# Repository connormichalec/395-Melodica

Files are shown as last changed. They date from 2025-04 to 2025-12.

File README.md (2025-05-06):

# 395-Melodica

Current setup, Key decoding (and to midi) on the smaller stm chip, looping jankily combined on bigger stm chip that was originally just going to be used for synthesis. Smaller ship sends midi data to synthesis. Synthesis manages looping and sends back midi data for smaller one to route to the output. TODO: Either re-seperate using a smaller chip with bigger ram (ideal). Or just get rid of smaller one together.

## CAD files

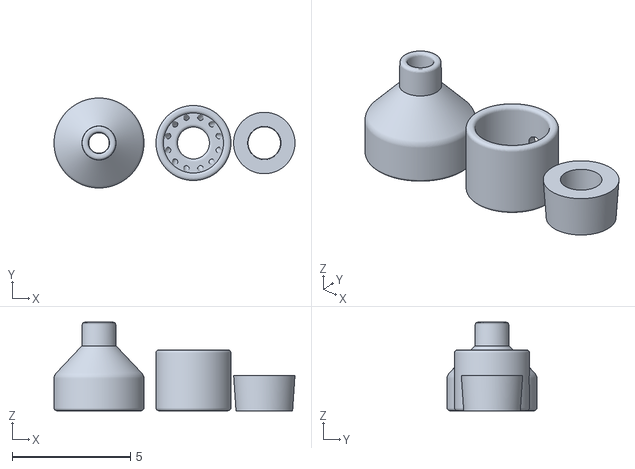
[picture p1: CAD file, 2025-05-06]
3D_Print_files/breath sensor 2.stl
10.2 x 3.81 x 3.75

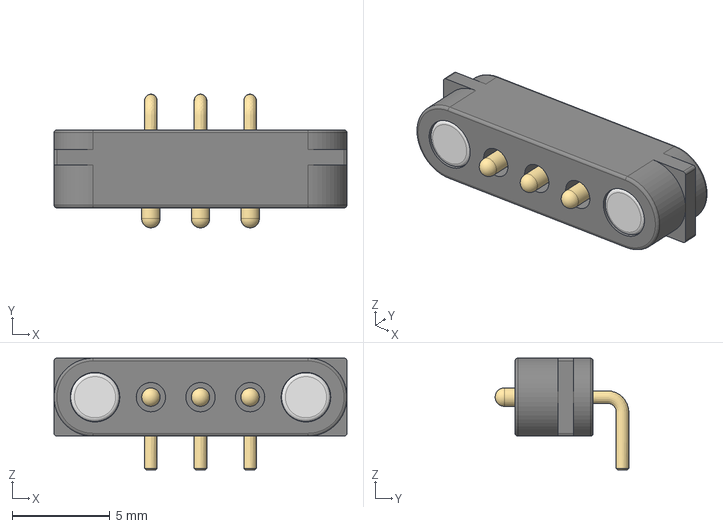
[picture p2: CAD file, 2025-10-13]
PCBs/V2/Switchbox/V1_Prototype_template/Symbols_footprints/5360/3D/5360.stp
15.0 x 6.84 x 5.73 mm

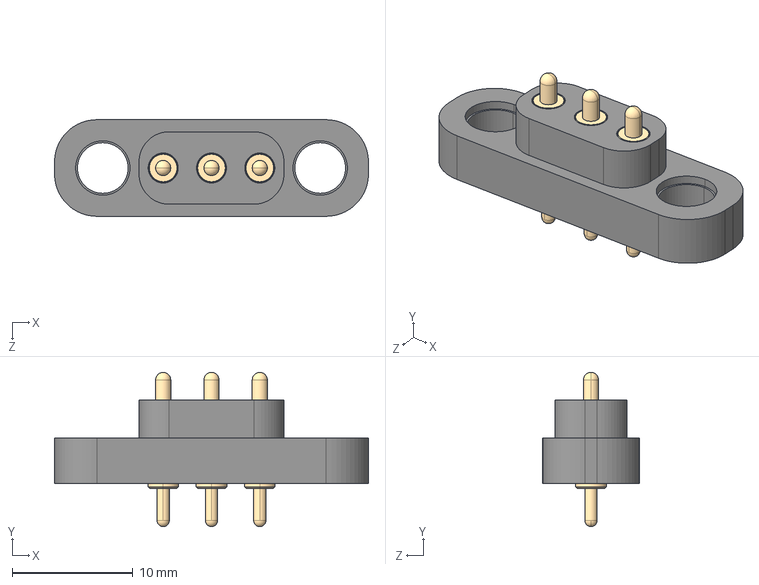
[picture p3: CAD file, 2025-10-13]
PCBs/V2/Switchbox/V1_Prototype_template/Symbols_footprints/858-22-003-10-001101/3D/858-22-003-10-001101.stp
26.0 x 12.8 x 8.00 mm
mill-max-858-22-003-10-001101_P8XX-18-014-16-08000X(P803-18-014-16-080000)
mill-max-858-22-003-10-001101_0858 x 3

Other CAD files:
PCBs/V2/Switchbox/V1_Prototype_template/Symbols_footprints/5360/Allegro/5360.psm
PCBs/V2/Switchbox/V1_Prototype_template/Symbols_footprints/5360/DEHDL/5360/chips/chips.prt
PCBs/V2/Switchbox/V1_Prototype_template/Symbols_footprints/858-22-003-10-001101/Allegro/8582200310001101.psm
PCBs/V2/Switchbox/V1_Prototype_template/Symbols_footprints/858-22-003-10-001101/DEHDL/858_22_003_10_001101/chips/chips.prt

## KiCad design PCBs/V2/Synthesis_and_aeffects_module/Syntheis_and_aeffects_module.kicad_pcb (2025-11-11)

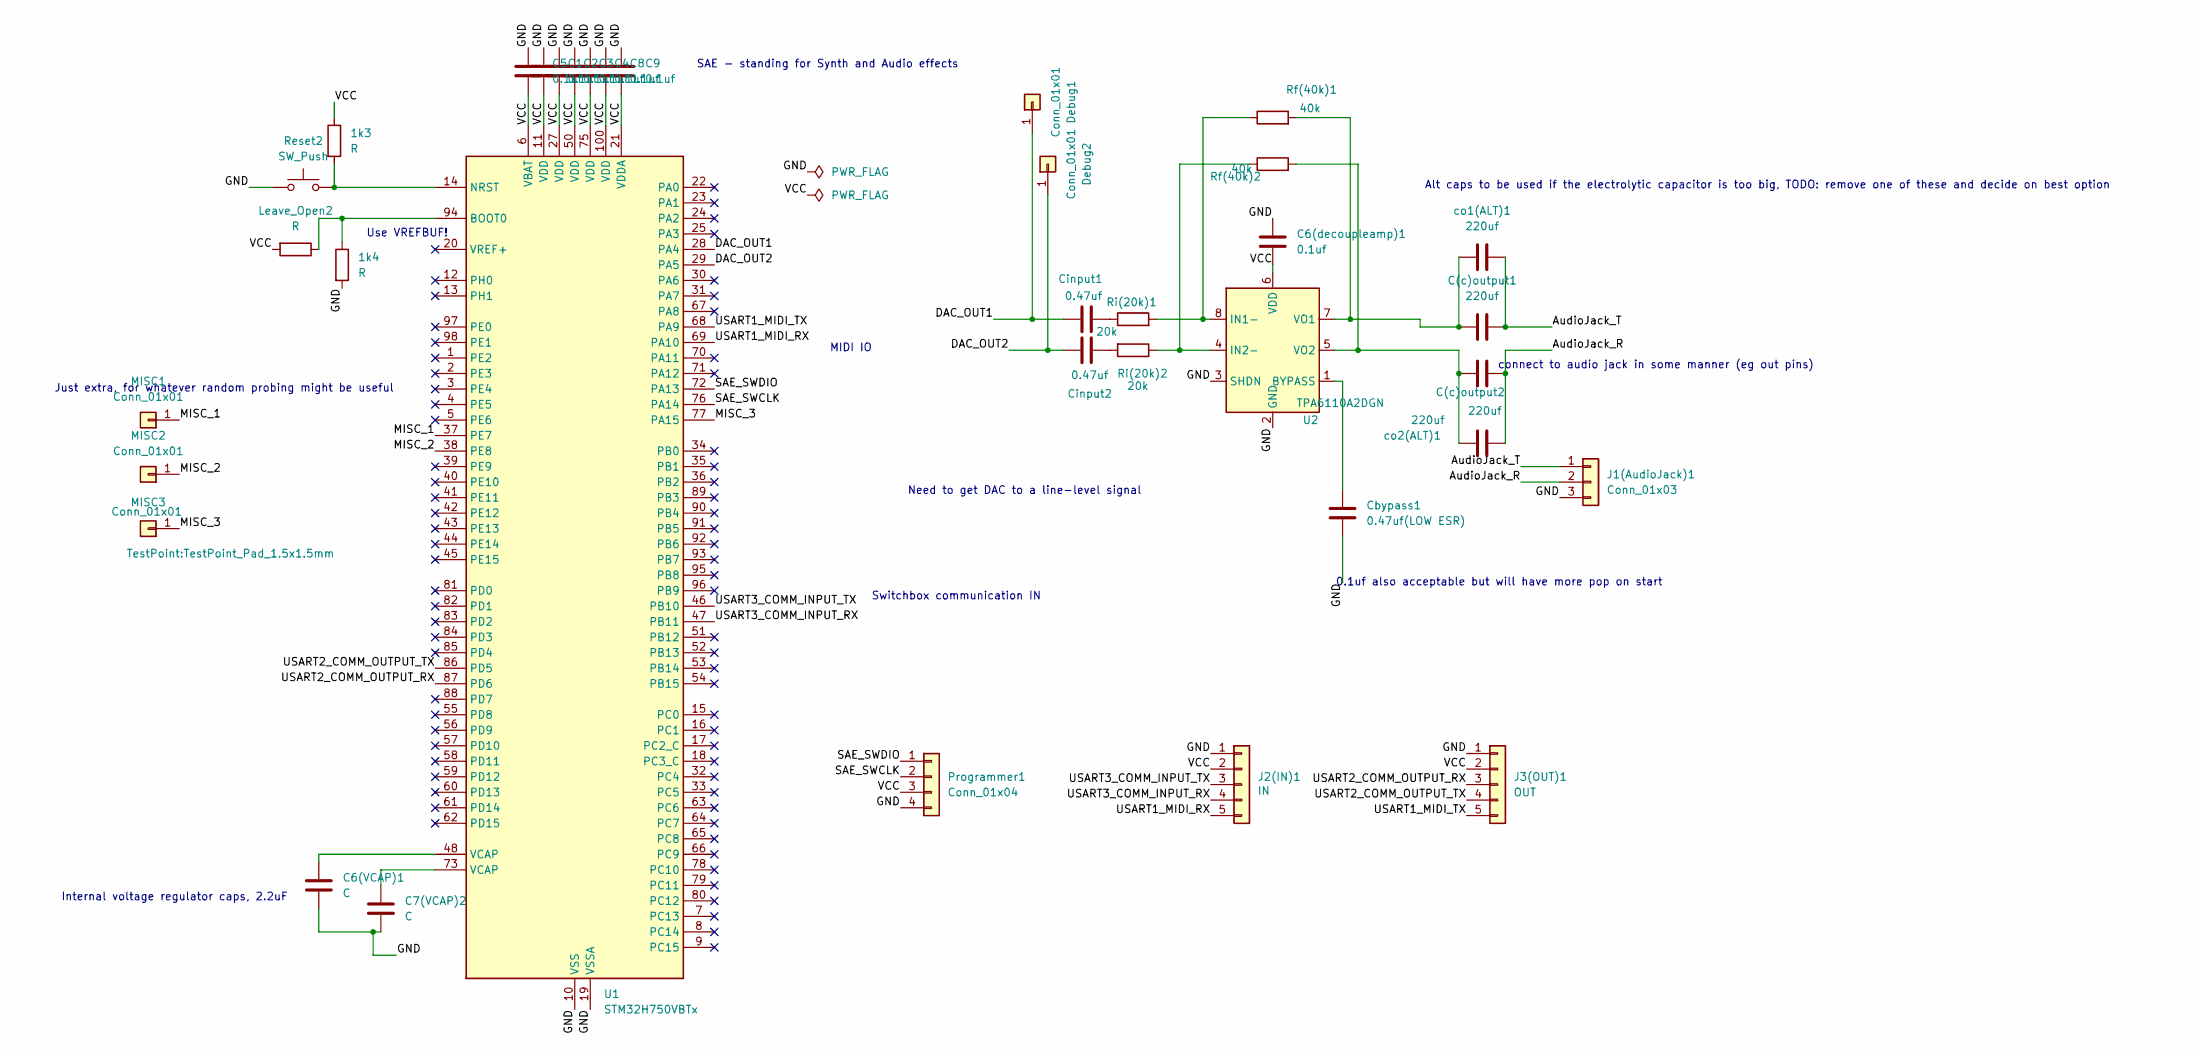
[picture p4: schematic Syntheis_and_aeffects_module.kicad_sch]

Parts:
1k3, 1k4: R; R_0603_1608Metric_Pad0.98x0.95mm_HandSolder
C1, C2, C3, C4, C5, C6(decoupleamp)1, C8, C9: 0.1uf; C_0603_1608Metric_Pad1.08x0.95mm_HandSolder
C6(VCAP)1, C7(VCAP)2: C; C_0603_1608Metric_Pad1.08x0.95mm_HandSolder
C(c)output1, C(c)output2: 220uf; CP_Radial_D5.0mm_P2.00mm
Cbypass1: 0.47uf(LOW ESR); C_0603_1608Metric_Pad1.08x0.95mm_HandSolder
Cinput1, Cinput2: 0.47uf; C_0603_1608Metric_Pad1.08x0.95mm_HandSolder
Debug1, Debug2: Conn_01x01; TestPoint_Pad_1.5x1.5mm
J1(AudioJack)1: Conn_01x03; PinHeader_1x03_P2.54mm_Vertical
J2(IN)1: IN; PinHeader_1x05_P2.54mm_Vertical
J3(OUT)1: OUT; PinHeader_1x05_P2.54mm_Vertical
Leave_Open2: R; R_Axial_DIN0204_L3.6mm_D1.6mm_P7.62mm_Horizontal
MISC1, MISC2, MISC3: Conn_01x01; TestPoint_Pad_1.5x1.5mm
Programmer1: Conn_01x04; PinHeader_1x04_P2.54mm_Vertical
Reset2: SW_Push; SW_PUSH_6mm_H4.3mm
Rf(40k)1, Rf(40k)2: 40k; R_Axial_DIN0207_L6.3mm_D2.5mm_P10.16mm_Horizontal
Ri(20k)1, Ri(20k)2: 20k; R_Axial_DIN0207_L6.3mm_D2.5mm_P10.16mm_Horizontal
U1: STM32H750VBTx; LQFP-100_14x14mm_P0.5mm
U2: TPA6110A2DGN; HVSSOP-8-1EP_3x3mm_P0.65mm_EP1.57x1.89mm
co1(ALT)1, co2(ALT)1: 220uf; C_1206_3216Metric_Pad1.33x1.80mm_HandSolder

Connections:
/AudioJack_R: C(c)output2.2, J1(AudioJack)1.2, co2(ALT)1.2
/AudioJack_T: C(c)output1.2, J1(AudioJack)1.1, co1(ALT)1.2
/DAC_OUT1: Cinput1.1, Debug1.1, U1.28 (PA4)
/DAC_OUT2: Cinput2.1, Debug2.1, U1.29 (PA5)
/GND: 1k4.2, C1.1, C2.1, C3.1, C4.1, C5.1, C6(VCAP)1.2, C6(decoupleamp)1.1, C7(VCAP)2.2, C8.1, C9.1, Cbypass1.2, J1(AudioJack)1.3, J2(IN)1.1, J3(OUT)1.1, Programmer1.4, Reset2.1, U1.10 (VSS), U1.19 (VSSA), U1.26 (VSS), U1.49 (VSS), U1.74 (VSS), U1.99 (VSS), U2.2 (GND), U2.3 (SHDN), U2.9 (GND)
/MISC_1: MISC1.1, U1.37 (PE7)
/MISC_2: MISC2.1, U1.38 (PE8)
/MISC_3: MISC3.1, U1.77 (PA15)
/SAE_SWCLK: Programmer1.2, U1.76 (PA14)
/SAE_SWDIO: Programmer1.1, U1.72 (PA13)
/USART1_MIDI_RX: J2(IN)1.5, U1.69 (PA10)
/USART1_MIDI_TX: J3(OUT)1.5, U1.68 (PA9)
/USART2_COMM_OUTPUT_RX: J3(OUT)1.3, U1.87 (PD6)
/USART2_COMM_OUTPUT_TX: J3(OUT)1.4, U1.86 (PD5)
/USART3_COMM_INPUT_RX: J2(IN)1.4, U1.47 (PB11)
/USART3_COMM_INPUT_TX: J2(IN)1.3, U1.46 (PB10)
/VCC: 1k3.1, C1.2, C2.2, C3.2, C4.2, C5.2, C6(decoupleamp)1.2, C8.2, C9.2, J2(IN)1.2, J3(OUT)1.2, Leave_Open2.2, Programmer1.3, U1.6 (VBAT), U1.11 (VDD), U1.21 (VDDA), U1.27 (VDD), U1.50 (VDD), U1.75 (VDD), U1.100 (VDD), U2.6 (VDD)
unnamed: C6(VCAP)1.1, U1.48 (VCAP)
unnamed: C7(VCAP)2.1, U1.73 (VCAP)
unnamed: Cinput1.2, Ri(20k)1.1
unnamed: Cinput2.2, Ri(20k)2.2
unnamed: 1k4.1, Leave_Open2.1, U1.94 (BOOT0)
unnamed: 1k3.2, Reset2.2, U1.14 (NRST)
unnamed: Cbypass1.1, U2.1 (BYPASS)
unnamed: Rf(40k)1.1, Ri(20k)1.2, U2.8 (IN1-)
unnamed: Rf(40k)2.1, Ri(20k)2.1, U2.4 (IN2-)
unnamed: C(c)output1.1, Rf(40k)1.2, U2.7 (VO1), co1(ALT)1.1
unnamed: C(c)output2.1, Rf(40k)2.2, U2.5 (VO2), co2(ALT)1.1

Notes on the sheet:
Switchbox communication IN
Need to get DAC to a line-level signal
connect to audio jack in some manner (eg out pins)
0.1uf also acceptable but will have more pop on start
SAE - standing for Synth and Audio effects
MIDI IO
Internal voltage regulator caps, 2.2uF
Alt caps to be used if the electrolytic capacitor is too big, TODO: remove one of these and decide on best option
Use VREFBUF!
Just extra, for whatever random probing might be useful

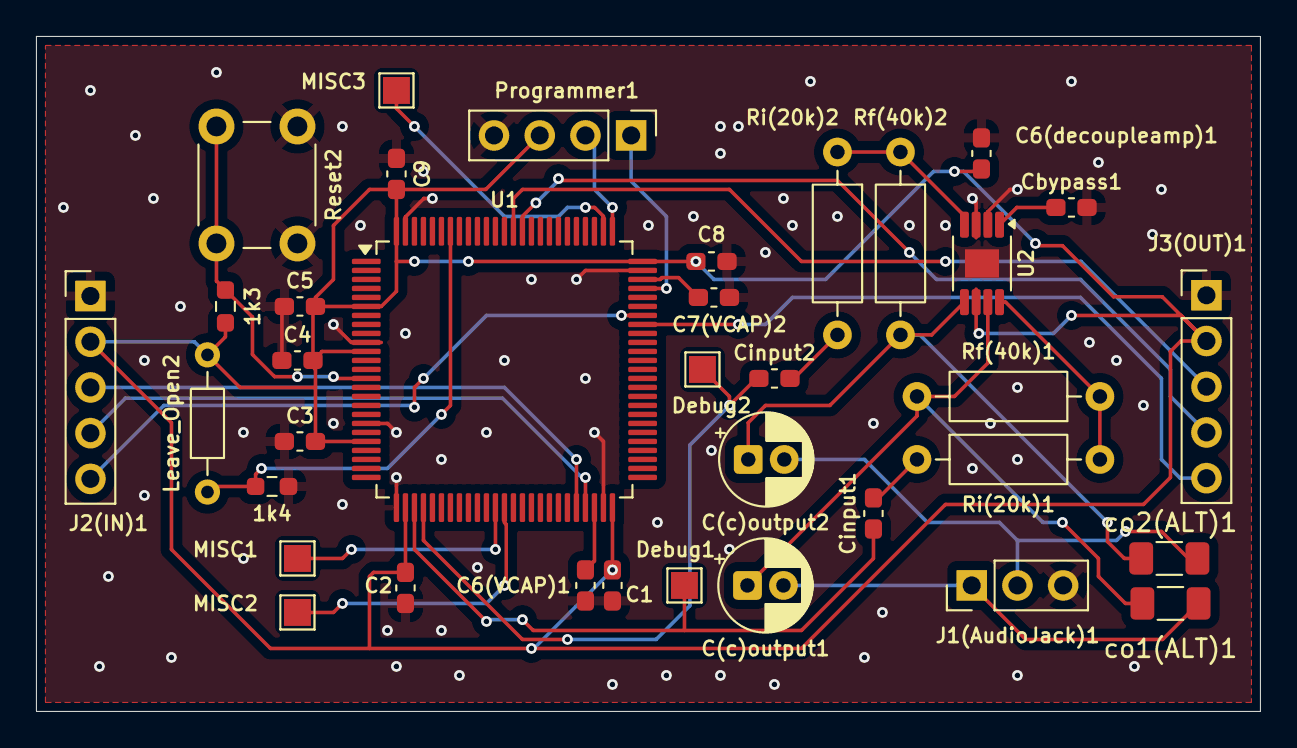
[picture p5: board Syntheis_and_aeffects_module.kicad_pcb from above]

Board: 2 copper layers, 68.0 x 37.5 mm, 36 parts (0 on the bottom side), 28 nets.

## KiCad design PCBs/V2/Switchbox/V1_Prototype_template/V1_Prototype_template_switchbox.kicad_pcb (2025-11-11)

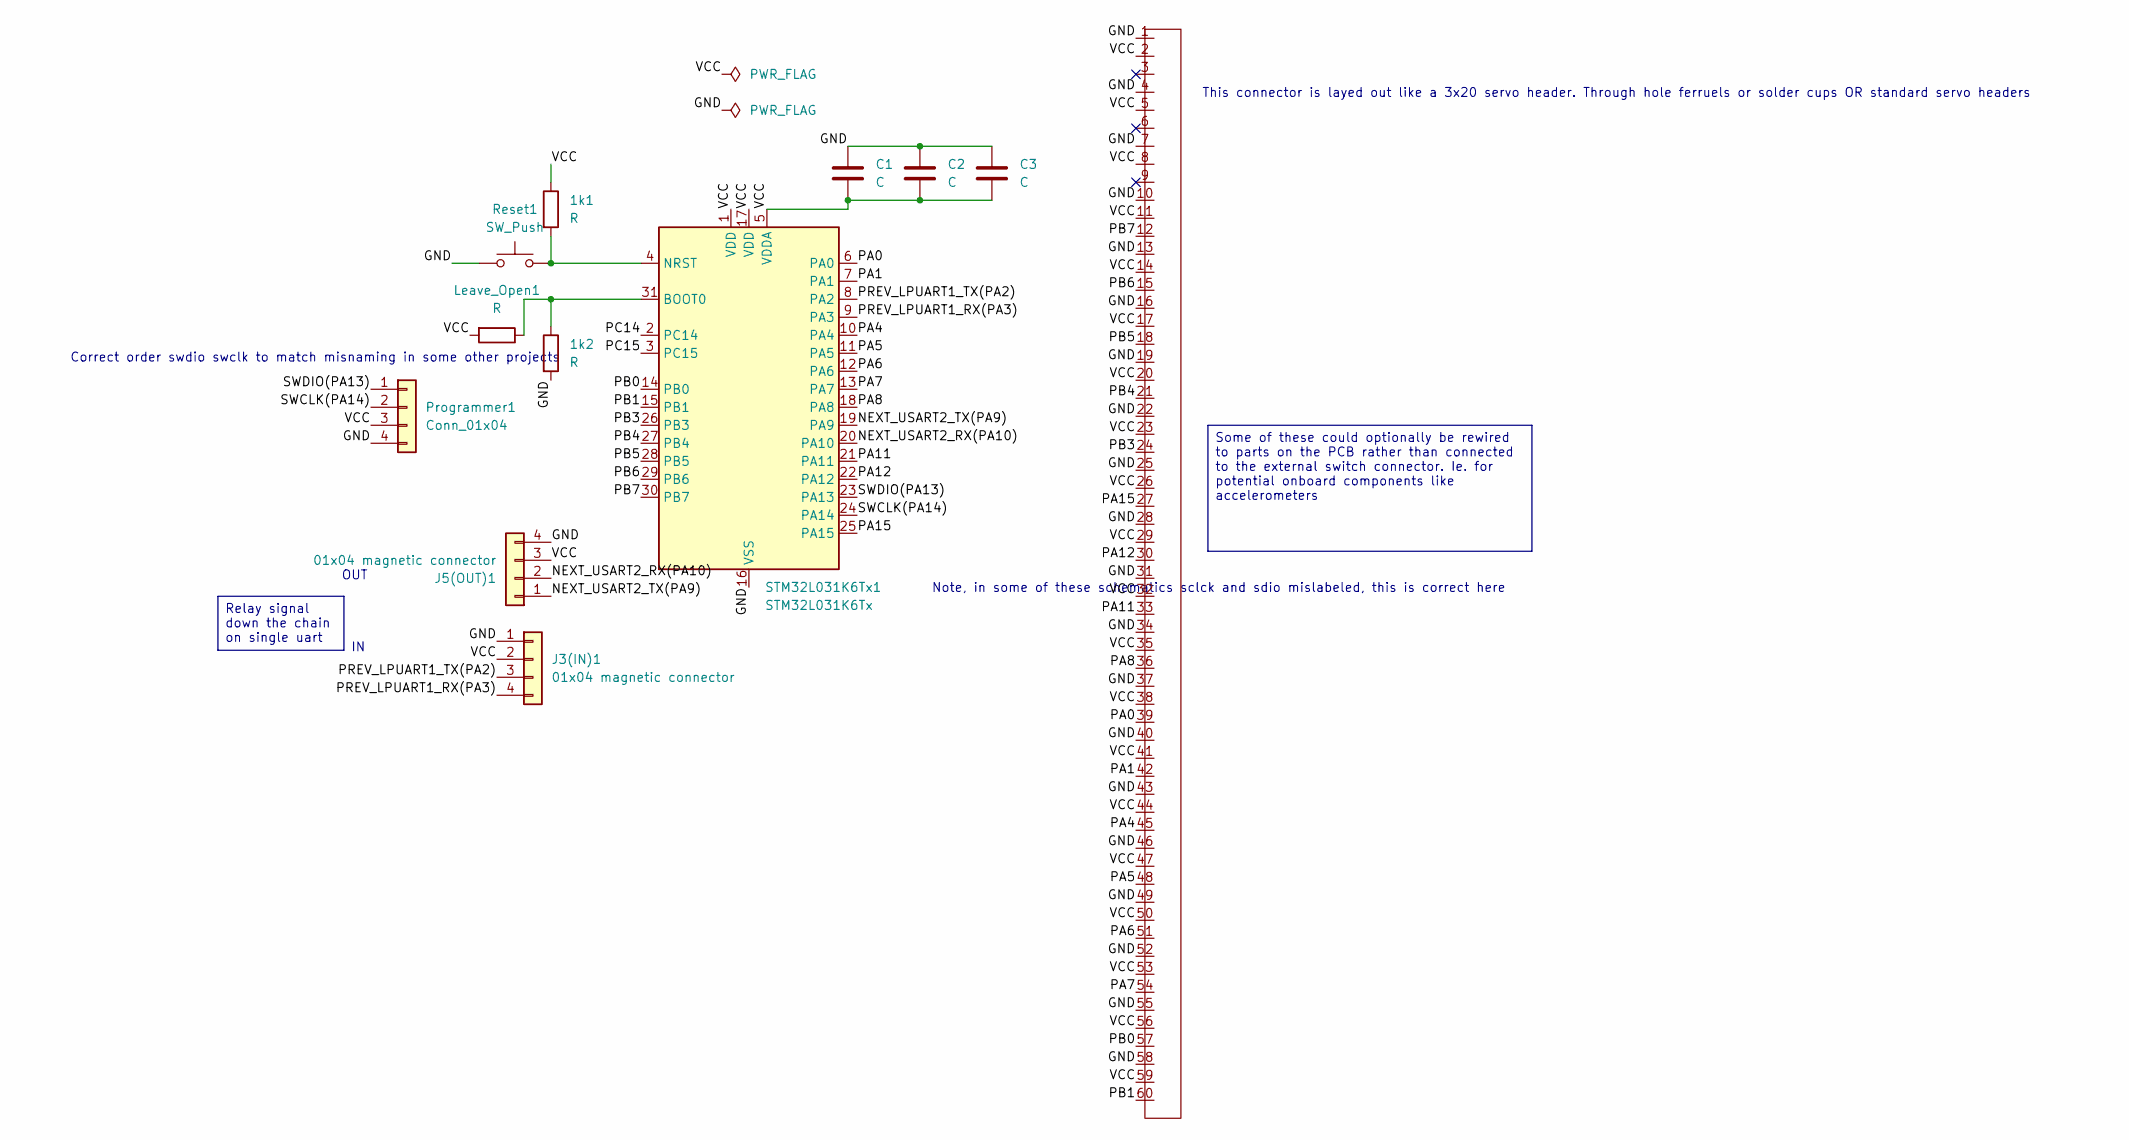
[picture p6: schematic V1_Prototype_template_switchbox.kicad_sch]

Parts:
1k1, 1k2: R; R_0603_1608Metric_Pad0.98x0.95mm_HandSolder
C1, C2, C3: C; C_0603_1608Metric
J3(IN)1, J5(OUT)1: 01x04 magnetic connector; 5358_4pin_connector_customfootprint
Leave_Open1: R; R_0603_1608Metric_Pad0.98x0.95mm_HandSolder
Programmer1: Conn_01x04; PinHeader_1x04_P2.54mm_Vertical
Reset1: SW_Push; SW_PUSH_6mm_H4.3mm
STM32L031K6Tx1: STM32L031K6Tx; LQFP-32_7x7mm_P0.8mm
U1: PinHeader_03x20

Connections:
/GND: 1k2.2, C1.1, C2.1, C3.1, J3(IN)1.1, J5(OUT)1.4, Programmer1.4, Reset1.1, STM32L031K6Tx1.16 (VSS), STM32L031K6Tx1.32 (VSS), U1.1, U1.4, U1.7, U1.10, U1.13, U1.16, U1.19, U1.22, U1.25, U1.28, U1.31, U1.34, U1.37, U1.40, U1.43, U1.46, U1.49, U1.52, U1.55, U1.58
/NEXT_USART2_RX(PA10): J5(OUT)1.2, STM32L031K6Tx1.20 (PA10)
/NEXT_USART2_TX(PA9): J5(OUT)1.1, STM32L031K6Tx1.19 (PA9)
/PA0: STM32L031K6Tx1.6 (PA0), U1.39
/PA1: STM32L031K6Tx1.7 (PA1), U1.42
/PA4: STM32L031K6Tx1.10 (PA4), U1.45
/PA5: STM32L031K6Tx1.11 (PA5), U1.48
/PA6: STM32L031K6Tx1.12 (PA6), U1.51
/PA7: STM32L031K6Tx1.13 (PA7), U1.54
/PA8: STM32L031K6Tx1.18 (PA8), U1.36
/PA11: STM32L031K6Tx1.21 (PA11), U1.33
/PA12: STM32L031K6Tx1.22 (PA12), U1.30
/PA15: STM32L031K6Tx1.25 (PA15), U1.27
/PB0: STM32L031K6Tx1.14 (PB0), U1.57
/PB1: STM32L031K6Tx1.15 (PB1), U1.60
/PB3: STM32L031K6Tx1.26 (PB3), U1.24
/PB4: STM32L031K6Tx1.27 (PB4), U1.21
/PB5: STM32L031K6Tx1.28 (PB5), U1.18
/PB6: STM32L031K6Tx1.29 (PB6), U1.15
/PB7: STM32L031K6Tx1.30 (PB7), U1.12
/PC14: STM32L031K6Tx1.2 (PC14)
/PC15: STM32L031K6Tx1.3 (PC15)
/PREV_LPUART1_RX(PA3): J3(IN)1.4, STM32L031K6Tx1.9 (PA3)
/PREV_LPUART1_TX(PA2): J3(IN)1.3, STM32L031K6Tx1.8 (PA2)
/SWCLK(PA14): Programmer1.2, STM32L031K6Tx1.24 (PA14)
/SWDIO(PA13): Programmer1.1, STM32L031K6Tx1.23 (PA13)
/VCC: 1k1.1, C1.2, C2.2, C3.2, J3(IN)1.2, J5(OUT)1.3, Leave_Open1.2, Programmer1.3, STM32L031K6Tx1.1 (VDD), STM32L031K6Tx1.5 (VDDA), STM32L031K6Tx1.17 (VDD), U1.2, U1.5, U1.8, U1.11, U1.14, U1.17, U1.20, U1.23, U1.26, U1.29, U1.32, U1.35, U1.38, U1.41, U1.44, U1.47, U1.50, U1.53, U1.56, U1.59
unnamed: 1k2.1, Leave_Open1.1, STM32L031K6Tx1.31 (BOOT0)
unnamed: 1k1.2, Reset1.2, STM32L031K6Tx1.4 (NRST)

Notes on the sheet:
Note, in some of these schematics sclck and sdio mislabeled, this is correct here
This connector is layed out like a 3x20 servo header. Through hole ferruels or solder cups OR standard servo headers
OUT
Correct order swdio swclk to match misnaming in some other projects
Relay signal down the chain on single uart
Some of these could optionally be rewired to parts on the PCB rather than connected to the external switch connector. Ie. for potential onboard components like accelerometers

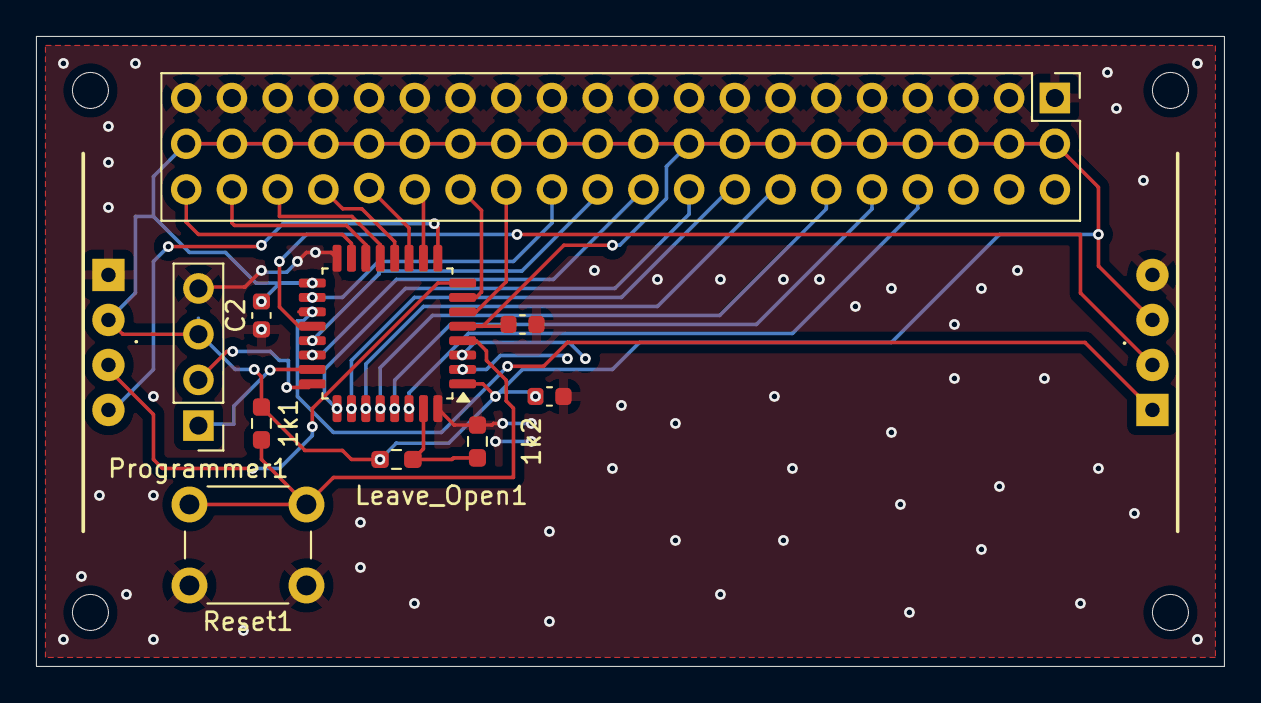
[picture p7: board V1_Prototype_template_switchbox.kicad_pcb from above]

Board: 2 copper layers, 66.0 x 35.0 mm, 12 parts (0 on the bottom side), 27 nets.

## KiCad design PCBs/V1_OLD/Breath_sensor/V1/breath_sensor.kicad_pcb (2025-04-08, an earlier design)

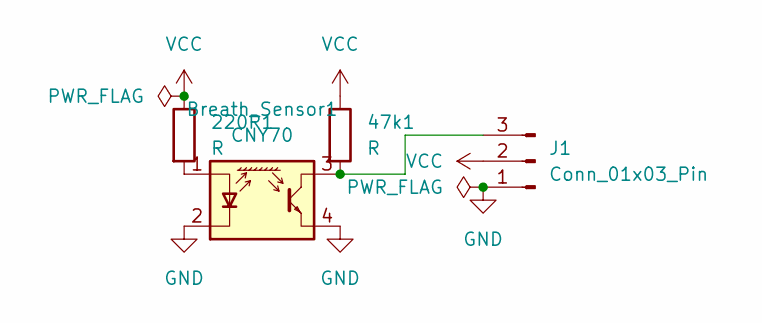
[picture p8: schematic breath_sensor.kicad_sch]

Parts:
47k1, 220R1: R; R_Axial_DIN0204_L3.6mm_D1.6mm_P7.62mm_Horizontal
Breath_Sensor1: CNY70; Vishay_CNY70
J1: Conn_01x03_Pin; PinHeader_1x03_P2.54mm_Horizontal

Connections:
GND: Breath_Sensor1.2 (K), Breath_Sensor1.4 (E), J1.1
unnamed: 220R1.2, Breath_Sensor1.1 (A)
unnamed: 47k1.2, Breath_Sensor1.3 (C), J1.3
VCC: 47k1.1, 220R1.1, J1.2

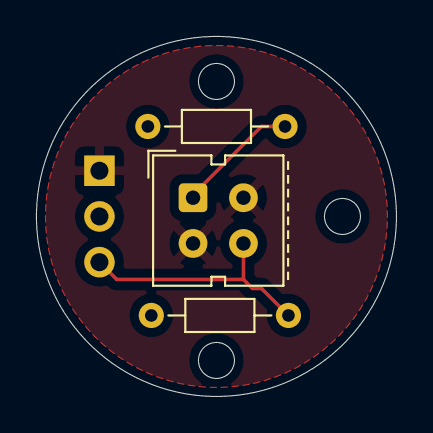
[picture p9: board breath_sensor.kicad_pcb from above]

Board: 2 copper layers, 20.0 x 20.0 mm, 4 parts (0 on the bottom side), 4 nets.

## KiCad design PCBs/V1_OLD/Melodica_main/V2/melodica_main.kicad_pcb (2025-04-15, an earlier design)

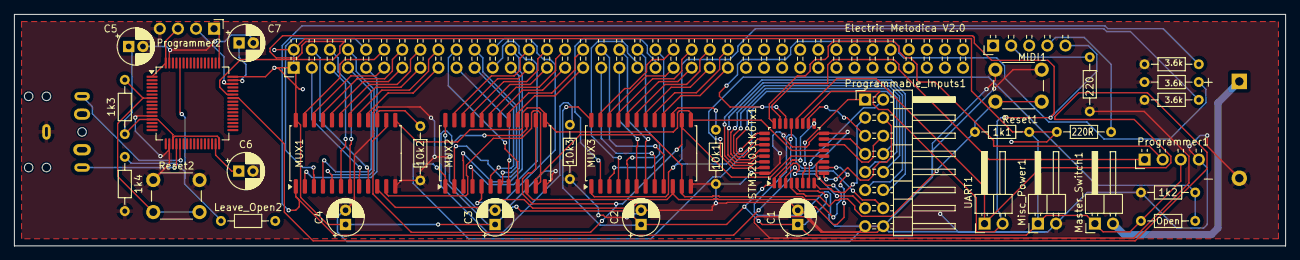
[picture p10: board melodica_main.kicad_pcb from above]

Board: 2 copper layers, 178.5 x 32.5 mm, 38 parts (0 on the bottom side), 91 nets.

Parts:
1k1, 1k2, 1k3, 1k4, 3.6k, 3.6k#2, 3.6k#3, 10k1, 10k2, 10k3, 220, 220R: R; R_Axial_DIN0204_L3.6mm_D1.6mm_P7.62mm_Horizontal
BT1: Battery; BatteryHolder_MPD_BC2AAPC_2xAA
C1, C2, C3, C4, C5, C6, C7: C; CP_Radial_D5.0mm_P2.00mm
J1: AudioJack3_SwitchTR; Jack_3.5mm_CUI_SJ1-3525N_Horizontal
Keys1: Conn_02x38_Odd_Even_Shielded; PinHeader_2x38_P2.54mm_Horizontal
Leave_Open2: R; R_Axial_DIN0204_L3.6mm_D1.6mm_P7.62mm_Horizontal
MIDI1: Conn_01x05; PinHeader_1x05_P2.54mm_Horizontal
MUX1, MUX2, MUX3: CD74HC4067M; SOIC-24W_7.5x15.4mm_P1.27mm
Master_Switch1: Conn_01x02; PinHeader_1x02_P2.54mm_Horizontal
Misc_Power1: Conn_01x02; PinHeader_1x02_P2.54mm_Horizontal
Open: R; R_Axial_DIN0204_L3.6mm_D1.6mm_P7.62mm_Horizontal
Programmable_Inputs1: Conn_02x08_Odd_Even; PinHeader_2x08_P2.54mm_Horizontal
Programmer1, Programmer2: Conn_01x04; PinHeader_1x04_P2.54mm_Horizontal
Reset1, Reset2: SW_Push; SW_PUSH_6mm_H4.3mm
STM32L031K6Tx1: STM32L031K6Tx; LQFP-32_7x7mm_P0.8mm
U1: STM32F405RGTx; LQFP-64_10x10mm_P0.5mm
UART1: Conn_01x02_Pin; PinHeader_1x02_P2.54mm_Horizontal

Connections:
/DAC1_SYNTH: J1.T, U1.20 (PA4)
/DAC2_SYNTH: J1.R, U1.21 (PA5)
/IN_0: 3.6k.2, MUX1.1 (COM), STM32L031K6Tx1.21 (PA11)
/IN_1: 3.6k#2.1, MUX2.1 (COM), STM32L031K6Tx1.22 (PA12)
/IN_2: 3.6k#3.2, MUX3.1 (COM), STM32L031K6Tx1.25 (PA15)
/N0: Keys1.4, MUX1.9 (I0)
/N1: Keys1.3, MUX1.8 (I1)
/N2: Keys1.6, MUX1.7 (I2)
/N3: Keys1.5, MUX1.6 (I3)
/N4: Keys1.8, MUX1.5 (I4)
/N5: Keys1.7, MUX1.4 (I5)
/N6: Keys1.10, MUX1.3 (I6)
/N7: Keys1.9, MUX1.2 (I7)
/N8: Keys1.12, MUX1.23 (I8)
/N9: Keys1.11, MUX1.22 (I9)
/N10: Keys1.14, MUX1.21 (I10)
/N11: Keys1.13, MUX1.20 (I11)
/N12: Keys1.16, MUX1.19 (I12)
/N13: Keys1.15, MUX1.18 (I13)
/N14: Keys1.18, MUX1.17 (I14)
/N15: Keys1.17, MUX1.16 (I15)
/N16: Keys1.20, MUX2.9 (I0)
/N17: Keys1.19, MUX2.8 (I1)
/N18: Keys1.22, MUX2.7 (I2)
/N19: Keys1.21, MUX2.6 (I3)
/N20: Keys1.24, MUX2.5 (I4)
/N21: Keys1.23, MUX2.4 (I5)
/N22: Keys1.26, MUX2.3 (I6)
/N23: Keys1.25, MUX2.2 (I7)
/N24: Keys1.28, MUX2.23 (I8)
/N25: Keys1.27, MUX2.22 (I9)
/N26: Keys1.30, MUX2.21 (I10)
/N27: Keys1.29, MUX2.20 (I11)
/N28: Keys1.32, MUX2.19 (I12)
/N29: Keys1.31, MUX2.18 (I13)
/N30: Keys1.34, MUX2.17 (I14)
/N31: Keys1.33, MUX2.16 (I15)
/N32: Keys1.36, MUX3.9 (I0)
/N33: Keys1.35, MUX3.8 (I1)
/N34: Keys1.38, MUX3.7 (I2)
/N35: Keys1.37, MUX3.6 (I3)
/N36: Keys1.40, MUX3.5 (I4)
/N37: Keys1.39, MUX3.4 (I5)
/N38: Keys1.42, MUX3.3 (I6)
/N39: Keys1.41, MUX3.2 (I7)
/N40: Keys1.44, MUX3.23 (I8)
/N41: Keys1.43, MUX3.22 (I9)
/N42: Keys1.46, MUX3.21 (I10)
/N43: Keys1.45, MUX3.20 (I11)
/N44: Keys1.48, MUX3.19 (I12)
/N45: Keys1.47, MUX3.18 (I13)
/N46: Keys1.50, MUX3.17 (I14)
/N47: Keys1.49, MUX3.16 (I15)
/PA0: Programmable_Inputs1.1, STM32L031K6Tx1.6 (PA0)
/PA1: Programmable_Inputs1.2, STM32L031K6Tx1.7 (PA1)
/PA2: Programmable_Inputs1.3, STM32L031K6Tx1.8 (PA2)
/PA3: Programmable_Inputs1.4, STM32L031K6Tx1.9 (PA3)
/PA8: Programmable_Inputs1.5, STM32L031K6Tx1.18 (PA8)
/PB0: Programmable_Inputs1.6, STM32L031K6Tx1.14 (PB0)
/PB1: Programmable_Inputs1.7, STM32L031K6Tx1.15 (PB1)
/PB3: Programmable_Inputs1.8, STM32L031K6Tx1.26 (PB3)
/PB4: Programmable_Inputs1.9, STM32L031K6Tx1.27 (PB4)
/PB5: Programmable_Inputs1.10, STM32L031K6Tx1.28 (PB5)
/PB6: Programmable_Inputs1.11, STM32L031K6Tx1.29 (PB6)
/PB7: Programmable_Inputs1.12, STM32L031K6Tx1.30 (PB7)
/PC14: Programmable_Inputs1.13, STM32L031K6Tx1.2 (PC14)
/PC15: Programmable_Inputs1.14, STM32L031K6Tx1.3 (PC15)
/S0: MUX1.10 (S0), MUX2.10 (S0), MUX3.10 (S0), STM32L031K6Tx1.10 (PA4)
/S1: MUX1.11 (S1), MUX2.11 (S1), MUX3.11 (S1), STM32L031K6Tx1.11 (PA5)
/S2: MUX1.14 (S2), MUX2.14 (S2), MUX3.14 (S2), STM32L031K6Tx1.12 (PA6)
/S3: MUX1.13 (S3), MUX2.13 (S3), MUX3.13 (S3), STM32L031K6Tx1.13 (PA7)
/SWCLK_MAIN: Programmer1.1, STM32L031K6Tx1.23 (PA13)
/SWCLK_SYNTH: Programmer2.1, U1.49 (PA14)
/SWDIO_MAIN: Programmer1.2, STM32L031K6Tx1.24 (PA14)
/SWDIO_SYNTH: Programmer2.2, U1.46 (PA13)
/UART_RX_MAIN: STM32L031K6Tx1.20 (PA10), U1.42 (PA9), UART1.1
/UART_RX_SYNTH: MIDI1.5, STM32L031K6Tx1.19 (PA9), U1.43 (PA10), UART1.2
GND: 1k2.2, 1k4.2, 3.6k.1, 3.6k#2.2, 3.6k#3.1, 10k1.2, 10k2.1, 10k3.2, 220.1, BT1.2 (-), C1.2, C2.2, C3.2, C4.2, C5.2, C6.2, C7.2, J1.S, MUX1.12 (GND), MUX2.12 (GND), MUX3.12 (GND), Misc_Power1.2, Programmable_Inputs1.15, Programmable_Inputs1.16, Programmer1.4, Programmer2.4, Reset1.1, Reset2.1, STM32L031K6Tx1.16 (VSS), STM32L031K6Tx1.32 (VSS), U1.12 (VSSA), U1.18 (VSS), U1.63 (VSS)
unnamed: BT1.1 (+), Master_Switch1.2
unnamed: 220.2, MIDI1.2
unnamed: 220R.2, MIDI1.4
unnamed: 10k2.2, MUX1.15 (~E)
unnamed: 10k3.1, MUX2.15 (~E)
unnamed: 10k1.1, MUX3.15 (~E)
unnamed: 1k2.1, Open.1, STM32L031K6Tx1.31 (BOOT0)
unnamed: 1k1.2, Reset1.2, STM32L031K6Tx1.4 (NRST)
unnamed: 1k4.1, Leave_Open2.1, U1.60 (BOOT0)
unnamed: 1k3.2, Reset2.2, U1.7 (NRST)
unnamed: C6.1, U1.31 (VCAP_1)
unnamed: C7.1, U1.47 (VCAP_2)
VCC: 1k1.1, 1k3.1, 220R.1, C1.1, C2.1, C3.1, C4.1, C5.1, Keys1.1, Keys1.2, Leave_Open2.2, MUX1.24 (VCC), MUX2.24 (VCC), MUX3.24 (VCC), Master_Switch1.1, Misc_Power1.1, Open.2, Programmer1.3, Programmer2.3, STM32L031K6Tx1.1 (VDD), STM32L031K6Tx1.5 (VDDA), STM32L031K6Tx1.17 (VDD), U1.1 (VBAT), U1.13 (VDDA), U1.19 (VDD), U1.32 (VDD), U1.48 (VDD), U1.64 (VDD)

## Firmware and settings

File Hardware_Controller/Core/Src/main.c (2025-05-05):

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
/* Includes ------------------------------------------------------------------*/
#include "main.h"

/* USER CODE BEGIN Includes */
#include "midi.h"
#include "mux.h"
#include "adc.h"
#include "looper.h"
#include <stdio.h>
#include <stdlib.h>

/* USER CODE END Includes */

ADC_HandleTypeDef hadc;
DMA_HandleTypeDef hdma_adc;

UART_HandleTypeDef hlpuart1;
UART_HandleTypeDef huart2;

TIM_HandleTypeDef htim2;
TIM_HandleTypeDef htim21;

void SystemClock_Config(void);
static void MX_GPIO_Init(void);
static void MX_DMA_Init(void);
static void MX_USART2_UART_Init(void);
static void MX_TIM2_Init(void);
static void MX_ADC_Init(void);
static void MX_LPUART1_UART_Init(void);
static void MX_TIM21_Init(void);
/* USER CODE BEGIN 0 */

volatile uint16_t adc_reg;	// Register for holding adc value
uint16_t adc_exp_reg = 0;		// Holds previous output of exponential filter
uint8_t adc_conv_complete_flag = 0;

/* USER CODE END 0 */

/**
  * @brief  The application entry point.
  * @retval int
  */
int main(void)
{

  /* MCU Configuration--------------------------------------------------------*/

  /* Reset of all peripherals, Initializes the Flash interface and the Systick. */
  HAL_Init();

  /* Configure the system clock */
  SystemClock_Config();

  /* Initialize all configured peripherals */
  MX_GPIO_Init();
  MX_DMA_Init();
  MX_USART2_UART_Init();
  MX_TIM2_Init();
  MX_ADC_Init();
  MX_LPUART1_UART_Init();
  MX_TIM21_Init();
  /* USER CODE BEGIN 2 */

  HAL_GPIO_WritePin(GPIOB, GPIO_PIN_1, 1);
  HAL_ADCEx_Calibration_Start(&hadc, ADC_SINGLE_ENDED);
  HAL_ADC_Start_DMA(&hadc, (uint32_t*) &adc_reg, 1);
  /* USER CODE END 2 */

  /* Infinite loop */
  /* USER CODE BEGIN WHILE */

  HAL_TIM_Base_Start(&htim2);
  HAL_TIM_Base_Start(&htim21);
  MIDI_Init();

  note_debouncer_init();

  uint8_t notes[48];
  uint8_t pressure = 0;

  uint16_t breath_threshold;
  uint8_t BREATH_THRESHOLD_SET = 0;
  int16_t last_sent_pressure = 0;

  //char adc_string[50];
  while (1)
  {
	  ReadKeyboard(notes, pressure > 0);

	  if (adc_conv_complete_flag == 1) {
		  if (!BREATH_THRESHOLD_SET) {
			  BREATH_THRESHOLD_SET = 1;
			  breath_threshold = adc_reg + 10;
		  }
		  uint16_t filtered_adc = exponential_filter(adc_reg, adc_exp_reg, 800);
		  pressure = remap(filtered_adc, breath_threshold, 1, 5);
		  int16_t difference = last_sent_pressure - pressure;
		  if (difference < -3 || difference > 3) {
			  channel_pressure(0, pressure);
			  last_sent_pressure = pressure;
		  }
		  adc_conv_complete_flag = 0;
	  }
	  if (__HAL_TIM_GET_FLAG(&htim21, TIM_FLAG_UPDATE)) {
	  __HAL_TIM_CLEAR_FLAG(&htim21, TIM_FLAG_UPDATE);
	  	  button_tick();
	  	  tick_buttons();
	  }
	  //looper_tick();

    /* USER CODE END WHILE */

    /* USER CODE BEGIN 3 */
  }
  /* USER CODE END 3 */
}

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
/* USER CODE BEGIN 4 */

void HAL_ADC_ConvCpltCallback(ADC_HandleTypeDef* hadc) {
	adc_conv_complete_flag = 1;
}

/* USER CODE END 4 */
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


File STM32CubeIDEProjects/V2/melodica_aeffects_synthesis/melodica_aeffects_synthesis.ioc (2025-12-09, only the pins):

Mcu.UserName=STM32H750VBTx
PA10.Signal=USART1_RX
PA4.Signal=COMP_DAC11_group
PA5.Signal=COMP_DAC12_group
PA9.Signal=USART1_TX
PB10.Signal=USART3_TX
PB11.Signal=USART3_RX
PC9.Signal=S_TIM8_CH4
PD5.Signal=USART2_TX
PD6.Signal=USART2_RX
PE7.Signal=GPIO_Input

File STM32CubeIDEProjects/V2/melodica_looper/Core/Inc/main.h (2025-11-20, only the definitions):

#define NEXT_TX_Pin GPIO_PIN_2
#define NEXT_TX_GPIO_Port GPIOA
#define NEXT_RX_Pin GPIO_PIN_3
#define NEXT_RX_GPIO_Port GPIOA
#define LOOPER_IN1_Pin GPIO_PIN_12
#define LOOPER_IN1_GPIO_Port GPIOB
#define LOOPER_IN2_Pin GPIO_PIN_13
#define LOOPER_IN2_GPIO_Port GPIOB
#define TRANSPOSE_DOWN_Pin GPIO_PIN_14
#define TRANSPOSE_DOWN_GPIO_Port GPIOB
#define TRANSPOSE_UP_Pin GPIO_PIN_15
#define TRANSPOSE_UP_GPIO_Port GPIOB
#define PREV_TX_Pin GPIO_PIN_9
#define PREV_TX_GPIO_Port GPIOA
#define PREV_RX_Pin GPIO_PIN_10
#define PREV_RX_GPIO_Port GPIOA
#define MIDI_OUT_Pin GPIO_PIN_10
#define MIDI_OUT_GPIO_Port GPIOC
#define MIDI_IN_Pin GPIO_PIN_11
#define MIDI_IN_GPIO_Port GPIOC
#define PREV_USART USART1
#define NEXT_USART USART2

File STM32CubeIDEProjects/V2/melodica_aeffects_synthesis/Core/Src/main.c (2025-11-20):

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
/* Includes ------------------------------------------------------------------*/
#include "main.h"

/* USER CODE BEGIN Includes */
#include "audio.h"
#include "midi.h"
#include "controlstate.h"
#include "protocol.h"
#include "signal.h"
#include <stdlib.h>
/* USER CODE END Includes */


DAC_HandleTypeDef hdac1;
DMA_HandleTypeDef hdma_dac1_ch1;
DMA_HandleTypeDef hdma_dac1_ch2;

TIM_HandleTypeDef htim8;

UART_HandleTypeDef huart1;
UART_HandleTypeDef huart2;
UART_HandleTypeDef huart3;

void SystemClock_Config(void);
static void MPU_Config(void);
static void MX_GPIO_Init(void);
static void MX_DMA_Init(void);
static void MX_TIM8_Init(void);
static void MX_USART1_UART_Init(void);
static void MX_USART2_UART_Init(void);
static void MX_USART3_UART_Init(void);
static void MX_DAC1_Init(void);
/* USER CODE BEGIN 0 */

extern uint8_t midi_buffer;
void HAL_UART_RxCpltCallback(UART_HandleTypeDef *huart)
{
	// For MIDI:
    if (huart->Instance == USART1) { // Ensure this is USART1's interrupt
        // Restart UART reception to keep listening - this is important to do BEFORE processbyte because processbyte could start the synthesis and interrupts wont be enabled until event callback returns.
        HAL_UART_Receive_IT(&huart1, &midi_buffer, 1);

        MIDI_ProcessByte(midi_buffer); // Your custom MIDI parsing logic
    }

    // For Comms:
    if (huart->Instance == USART2) {
    	Next_ProcessByte();
    }

    if (huart->Instance == USART3) {
    	Prev_ProcessByte();

    }
}

/* USER CODE END 0 */

/**
  * @brief  The application entry point.
  * @retval int
  */
int main(void)
{

  /* MPU Configuration--------------------------------------------------------*/
  MPU_Config();

  /* MCU Configuration--------------------------------------------------------*/

  /* Reset of all peripherals, Initializes the Flash interface and the Systick. */
  HAL_Init();

  /* Configure the system clock */
  SystemClock_Config();

  /* Initialize all configured peripherals */
  MX_GPIO_Init();
  MX_DMA_Init();
  MX_TIM8_Init();
  MX_USART1_UART_Init();
  MX_USART2_UART_Init();
  MX_USART3_UART_Init();
  MX_DAC1_Init();
  /* USER CODE BEGIN 2 */
  MIDI_Init(&note_callbk);
  ProtocolInit();

  // For debugging: - good use in stm32f4xx_it.c it can be set to go high when hard fault occurs
	HAL_GPIO_WritePin(GPIOA, GPIO_PIN_15, 0);

  initialize_controlstate();
  audio_signal_init(&htim8, &hdac1);


  uint8_t* testbuffer = (uint8_t*) malloc(sizeof(uint8_t)*512);



  /* USER CODE END 2 */

  /* Infinite loop */
  /* USER CODE BEGIN WHILE */
  while (1)
  {
	  audio_signal_loop_tick();

	  if(HAL_GPIO_ReadPin(GPIOE, GPIO_PIN_7)) {
		  *((uint8_t*)testbuffer) = 0;
		  update_parameter(PARAMETER_ID_FILTER1_TYPE,0,testbuffer);
	  }
    /* USER CODE END WHILE */

    /* USER CODE BEGIN 3 */
  }
  /* USER CODE END 3 */
}

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
 /* MPU Configuration */

void MPU_Config(void)
{
  MPU_Region_InitTypeDef MPU_InitStruct = {0};

  /* Disables the MPU */
  HAL_MPU_Disable();

  /** Initializes and configures the Region and the memory to be protected
  */
  MPU_InitStruct.Enable = MPU_REGION_ENABLE;
  MPU_InitStruct.Number = MPU_REGION_NUMBER0;
  MPU_InitStruct.BaseAddress = 0x0;
  MPU_InitStruct.Size = MPU_REGION_SIZE_4GB;
  MPU_InitStruct.SubRegionDisable = 0x87;
  MPU_InitStruct.TypeExtField = MPU_TEX_LEVEL0;
  MPU_InitStruct.AccessPermission = MPU_REGION_NO_ACCESS;
  MPU_InitStruct.DisableExec = MPU_INSTRUCTION_ACCESS_DISABLE;
  MPU_InitStruct.IsShareable = MPU_ACCESS_SHAREABLE;
  MPU_InitStruct.IsCacheable = MPU_ACCESS_NOT_CACHEABLE;
  MPU_InitStruct.IsBufferable = MPU_ACCESS_NOT_BUFFERABLE;

  HAL_MPU_ConfigRegion(&MPU_InitStruct);
  /* Enables the MPU */
  HAL_MPU_Enable(MPU_PRIVILEGED_DEFAULT);

}

/**
  * @brief  This function is executed in case of error occurrence.
  * @retval None
  */
void Error_Handler(void)
{
  /* USER CODE BEGIN Error_Handler_Debug */
  /* User can add his own implementation to report the HAL error return state */
  __disable_irq();
  while (1)
  {
  }
  /* USER CODE END Error_Handler_Debug */
}

#ifdef  USE_FULL_ASSERT
/**
  * @brief  Reports the name of the source file and the source line number
  *         where the assert_param error has occurred.
  * @param  file: pointer to the source file name
  * @param  line: assert_param error line source number
  * @retval None
  */
void assert_failed(uint8_t *file, uint32_t line)
{
  /* USER CODE BEGIN 6 */
  /* User can add his own implementation to report the file name and line number,
     ex: printf("Wrong parameters value: file %s on line %d\r\n", file, line) */
  /* USER CODE END 6 */
}
#endif /* USE_FULL_ASSERT */

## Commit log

2025-03-28 Adjusting main.c to support adc
2025-03-28 More ADC stuff
2025-03-31 Breath sensor working
2025-04-02 MIDI Rx stuff and organ stop fix
    [midi.c, midi.h]
2025-04-04 synthesis progress, sawtooth wave, switched to a circular buffer
2025-04-04 Great progess on Synthesis, cleanwaveform using circular buffer and simple oscillator system built
    [audio.c, main.c]
2025-04-08 add pcb files
    [breath_sensor.kicad_pcb, breath_sensor.kicad_sch, melodica_main.kicad_pcb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]
2025-04-09 V2 PCB schematic done - added new synthesis STMF405
    [melodica_main.kicad_pcb, melodica_main.kicad_sch]
2025-04-10 V2 PCB design of melodica
    [melodica_main.kicad_pcb, melodica_main.kicad_sch]
2025-04-10 Continiued implementation of signal processing chain, implemented basic keyboard functionality, untested and needs to be refined. ADSR began implementation but needs redesign
    [audio.c, main.c, melodica_synthesis.ioc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]
2025-04-15 Good progress with synthesis, MIDI reception now works seamlessly. Big problem with DMA, potential race conditoins on filling buffer because randomly freezes up
    [audio.c, main.c, midi.c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]
2025-04-16 YAY! Hard fault issue was resolved by disabling interrupts temporarily (should eventually be replaced by a more professional soluiton), keyboard now works well!
    [audio.c, main.c, midi.c]
2025-04-22 No longer crashes when number of oscillators is exceeded!
    [audio.c, main.c, melodica_synthesis.ioc]
2025-04-27 basic logarithmic pressure control
2025-04-29 Changed how note pressure is handled to make more efficient
2025-04-30 Added low pass filters, (resonance is buggin
2025-04-30 added minimum to synth cutoff on the breath pressure demo
2025-05-05 Voice channel pressures
2025-05-06 Upload STL
    [breath sensor 2.stl]
2025-09-02 Added V2 schematic.drawio
2025-09-09 created melodica cad file and started editing
    [Melodica.FCStd, breath sensor 2.stl]
2025-09-09 F and E keys done
    [Melodica.FCStd]
2025-09-10 Melodica Cad update - all white keys done
    [Melodica.FCStd]
2025-09-16 Keys done, progress made on starting base of melodica
    [Melodica.FCStd]
2025-09-30 Progress on Case design for CAD, start on switchbox schematic
    [V1_Prototype_template_switchbox.kicad_pcb, V1_Prototype_template_switchbox.kicad_sch, breath_sensor.kicad_pcb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]
2025-09-30 some progress on switchbox schematic
    [V1_Prototype_template_switchbox.kicad_pcb, V1_Prototype_template_switchbox.kicad_sch]
2025-10-01 progress on switchboard schematic
    [5360.PcbLib, 5360.SchLib, 5360.psm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]
2025-10-02 good progress on switchbox pcb design
    [V1_Prototype_template_switchbox.kicad_pcb, V1_Prototype_template_switchbox.kicad_sch]
2025-10-07 PCB For switchbox prototype done
    [V1_Prototype_template_switchbox.kicad_pcb, V1_Prototype_template_switchbox.kicad_sch]
2025-10-07 fixed connector heights on switchbox pcb
    [V1_Prototype_template_switchbox.kicad_pcb]
2025-10-07 small fixes to switchbox pcb
    [V1_Prototype_template_switchbox.kicad_pcb, V1_Prototype_template_switchbox.kicad_sch]
2025-10-10 reorginization, started progess on synth_aeffects pcb
    [Syntheis_and_aeffects_module.kicad_pcb, Syntheis_and_aeffects_module.kicad_sch, breath_sensor.kicad_pcb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]
2025-10-11 CAD progress
2025-10-14 pcb progress
    [Syntheis_and_aeffects_module.kicad_pcb, Syntheis_and_aeffects_module.kicad_sch]
2025-10-15 schematic progress
    [Syntheis_and_aeffects_module.kicad_pcb, Syntheis_and_aeffects_module.kicad_sch]
2025-10-15 add meloica_looper stm32 project
2025-10-15 remove adiojack from schematic, replace with pin headers
    [Syntheis_and_aeffects_module.kicad_pcb, Syntheis_and_aeffects_module.kicad_sch]
2025-10-15 more progress on synthesis pcb
    [Syntheis_and_aeffects_module.kicad_pcb, Syntheis_and_aeffects_module.kicad_sch]
2025-10-17 some updates
    [Syntheis_and_aeffects_module.kicad_pcb, Syntheis_and_aeffects_module.kicad_sch, V1_Prototype_template_switchbox.kicad_pcb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]
2025-10-21 messed UART connection for synthesis PCB :/ good thing i had those misc pads for testing. Need to reorder.
    [Syntheis_and_aeffects_module.kicad_pcb, Syntheis_and_aeffects_module.kicad_sch, V1_Prototype_template_switchbox.kicad_pcb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]
2025-10-21 Switchbox pcb was also fucked up, fixed that, need to order now. (and tweaked the switchbox boilerplate code.
    [V1_Prototype_template_switchbox.kicad_pcb, V1_Prototype_template_switchbox.kicad_sch]
2025-10-23 Began implementation of control states for synthesis, we need a system to keep track of settings and allow updating those values based on switchbox input
2025-10-29 testing and fixing PCBs, reordered
    [V1_Prototype_template_switchbox.kicad_pcb, V1_Prototype_template_switchbox.kicad_sch]
2025-11-04 some updates for switchbox
2025-11-04 Progess with switchbox code
2025-11-06 IO Switchbox code implementation updates
2025-11-08 Added a misc struct to io object, allows passing of misc data to polling functions; also implemented a test design for 3 switches
2025-11-08 began implementation of potetiometers for switchbox
2025-11-08 some implementation on updating parameters especially with pots as fixed point representations to send over uart
2025-11-08 throw device id in there
2025-11-09 Progress on fx chip, Rx still not working
    [main.c, main.h, melodica_looper.ioc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]
2025-11-18 Working on switchbox stuff
2025-11-18 Attempting to fix switchbox rx
    [main.c, melodica_switchbox_boilerplate.ioc, modules.c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]
2025-11-19 some tests with switchbox->synth connectivity, seems basic connection is working
2025-11-20 Fixing up issues with protocol
    [modules.c, protocol.c]
2025-11-20 Fixing module rx on midifx board
    [main.c, main.h, melodica_looper.ioc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]
2025-12-01 Basic switchbox functionality tests with Synthesis, 3 way switch works! is able to select oscillator type
    [IODevices.c, main.c]
2025-12-05 all switches/pots implementedgit add .!
2025-12-09 System now (actually) sends an initial update when first powered on - fixed issue because sending a bunch of parameters one after another overloads synth receiver and it only updates the first
    [IODevices.c, main.c, protocol.c]
2025-12-09 changed some interrupt NVIC priorities (hopefully reduce pot crackling)
    [melodica_aeffects_synthesis.ioc]
2025-12-09 basic breath sensing working - some jankiness with setup tho need to fix
    [IODevices.c]

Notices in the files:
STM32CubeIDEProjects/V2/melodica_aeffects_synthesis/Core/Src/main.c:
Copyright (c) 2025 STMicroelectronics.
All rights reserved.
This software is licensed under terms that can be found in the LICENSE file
